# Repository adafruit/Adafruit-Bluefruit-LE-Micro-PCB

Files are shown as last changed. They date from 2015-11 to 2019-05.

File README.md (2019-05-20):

## Adafruit Bluefruit LE Micro PCB (Discontinued)
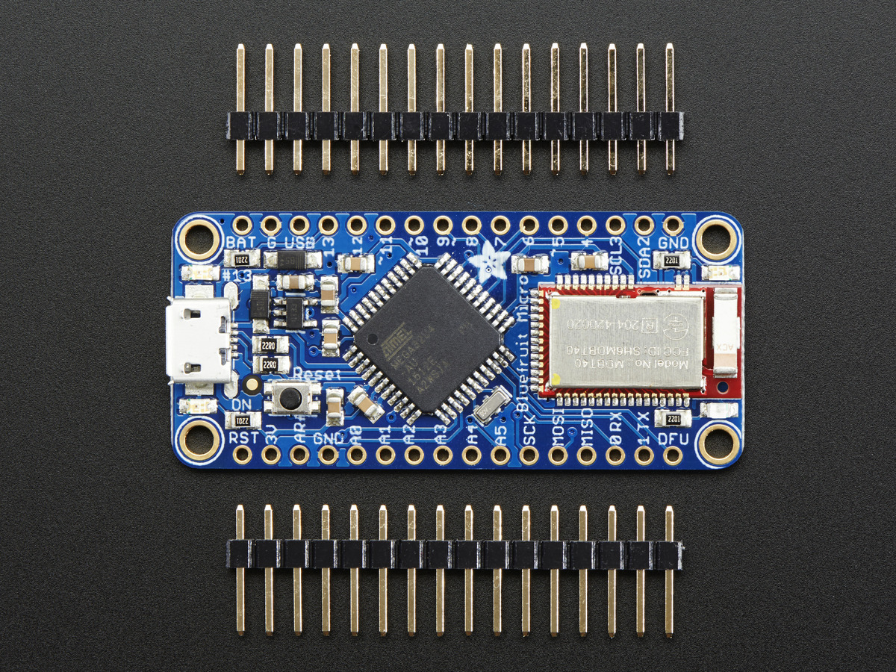
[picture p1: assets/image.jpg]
<a href="http://www.adafruit.com/products/2661"><br/>
See the part listing in the Adafruit shop</a>

DISCONTINUED
Check out the [Adafruit Feather 32u4 Bluefruit LE](https://www.adafruit.com/products/2829), it's an awesome upgrade!

PCB files for Adafruit Bluefruit LE Micro. Format is EagleCAD.
- https://www.adafruit.com/product/2661

### License

Adafruit invests time and resources providing this open source design, please support Adafruit and open-source hardware by purchasing products from [Adafruit](https://www.adafruit.com)!

All text above must be included in any redistribution

Designed by Limor Fried/Ladyada for Adafruit Industries.
Creative Commons Attribution/Share-Alike, all text above must be included in any redistribution. 
See license.txt for additional information.

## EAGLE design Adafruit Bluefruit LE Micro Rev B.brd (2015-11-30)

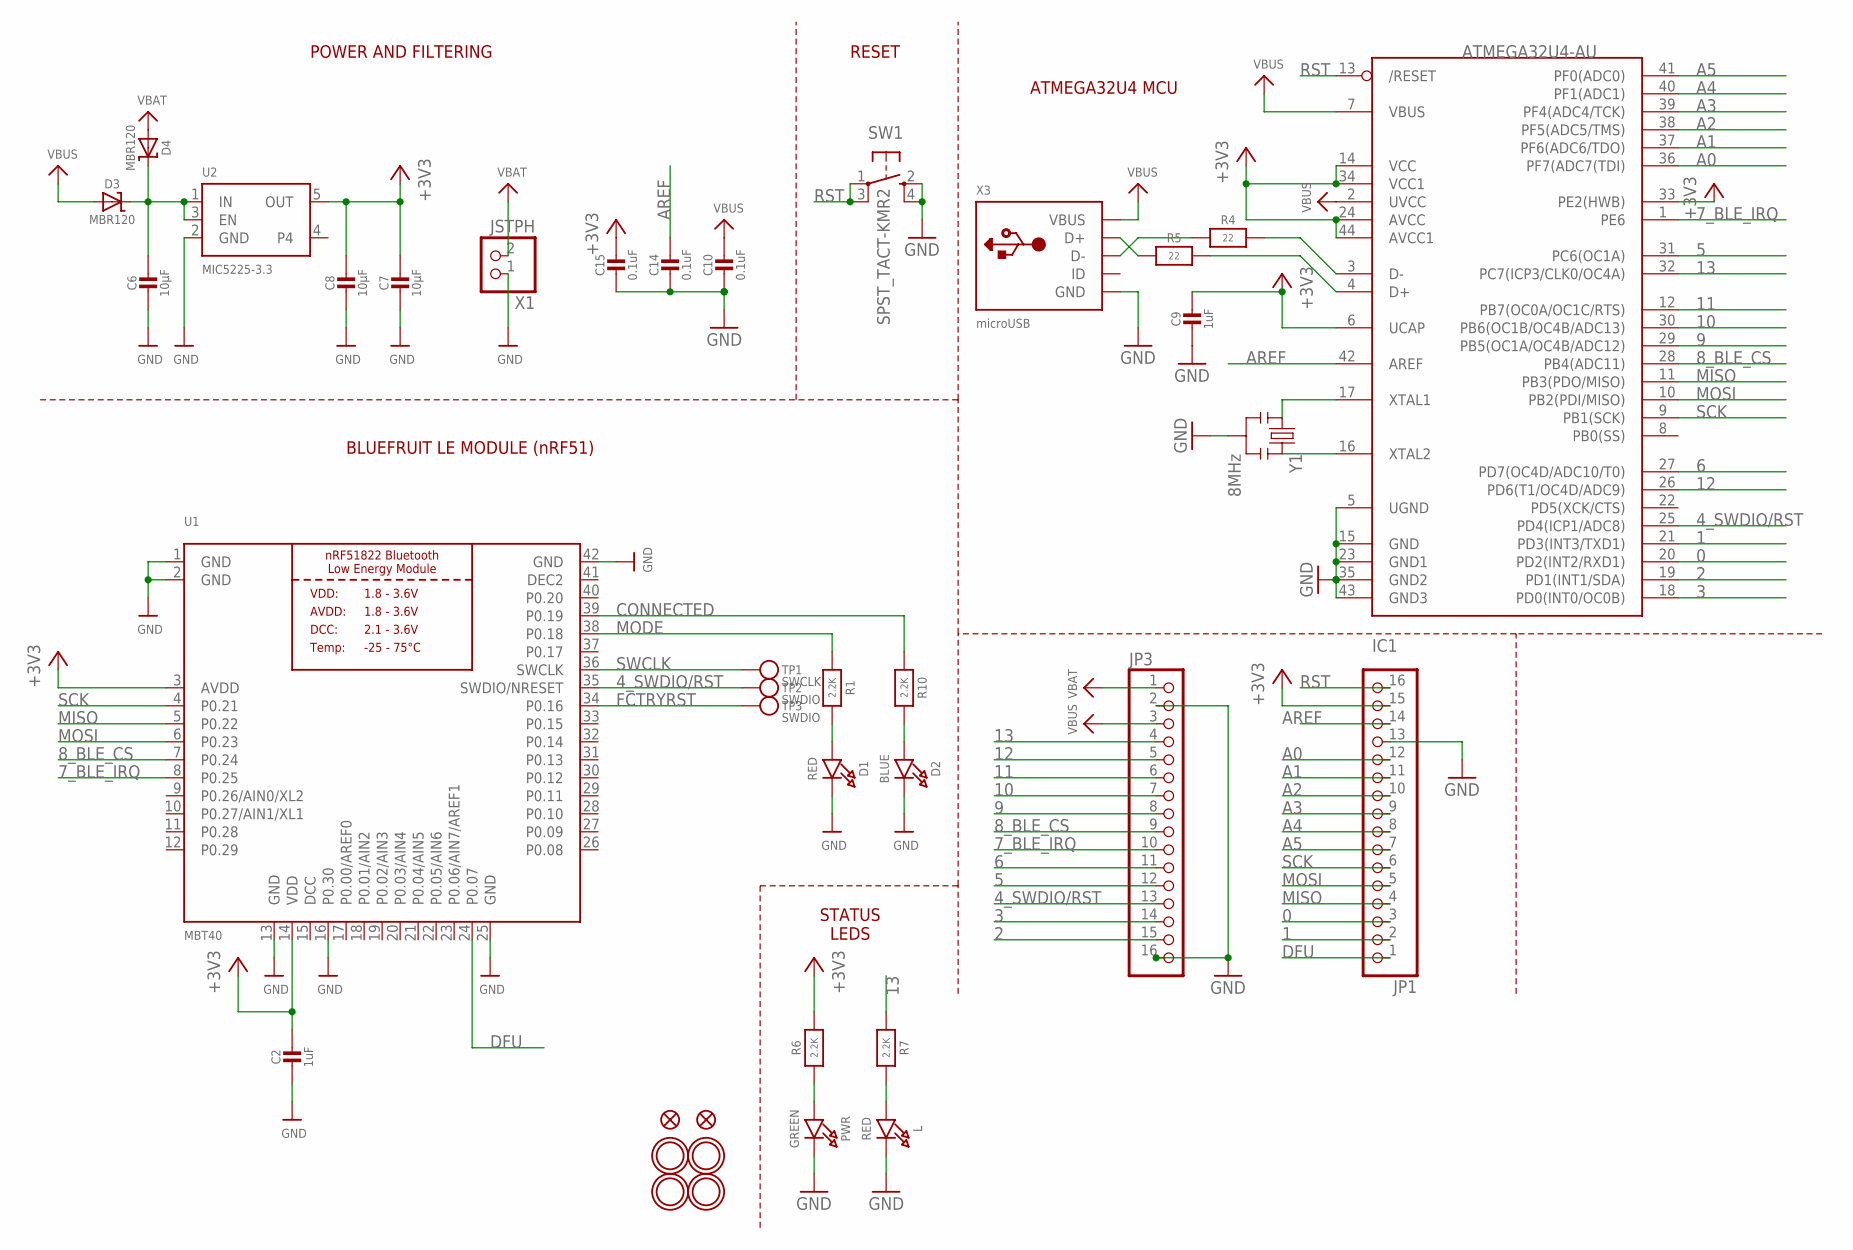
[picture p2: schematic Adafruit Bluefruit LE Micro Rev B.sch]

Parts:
C2, C9: 1uF; 0805-NO
C6: 10µF; _0805MP
C7, C8: 10µF; 0805-NO
C10: 0.1uF; 0805_10MGAP
C14, C15: 0.1uF; 0805-NO
D1: RED; CHIPLED_0805_NOOUTLINE
D2: BLUE; CHIPLED_0805_NOOUTLINE
D3, D4: MBR120; SOD-123
IC1: ATMEGA32U4-AU; TQFP44
JP1, JP3: HEADER-1X16ROUND; 1X16_ROUND
L: RED; CHIPLED_0805_NOOUTLINE
PWR: GREEN; CHIPLED_0805_NOOUTLINE
R1, R6, R7, R10: 2.2K; 0805-NO
R4, R5: 22; 0805-NO
SW1: SPST_TACT-KMR2; KMR2
TP1: SWCLK; PAD-1.5X2.0
TP2, TP3: SWDIO; PAD-1.5X2.0
U1: MBT40; BLE_MODULE_RAYTAC_MDBT40
U2: MIC5225-3.3; SOT23-5
U$6, U$24, U$31, U$32: MOUNTINGHOLE2.5; MOUNTINGHOLE_2.5_PLATED
U$34, U$35: FIDUCIAL""; FIDUCIAL_1MM
X1: JSTPH; JSTPH2
X3: microUSB; 4UCONN_20329
Y1: 8MHz; RESONATOR-SMD

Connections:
0: IC1.20 (PD2(INT2/RXD1)), JP1.3
1: IC1.21 (PD3(INT3/TXD1)), JP1.2
2: IC1.19 (PD1(INT1/SDA)), JP3.15
3: IC1.18 (PD0(INT0/OC0B)), JP3.14
4_SWDIO/RST: IC1.25 (PD4(ICP1/ADC8)), JP3.13, TP2.P$1, U1.35 (SWDIO/NRESET)
5: IC1.31 (PC6(OC1A)), JP3.12
6: IC1.27 (PD7(OC4D/ADC10/T0)), JP3.11
7_BLE_IRQ: IC1.1 (PE6), JP3.10, U1.8 (P0.25)
8_BLE_CS: IC1.28 (PB4(ADC11)), JP3.9, U1.7 (P0.24)
9: IC1.29 (PB5(OC1A/OC4B/ADC12)), JP3.8
10: IC1.30 (PB6(OC1B/OC4B/ADC13)), JP3.7
11: IC1.12 (PB7(OC0A/OC1C/RTS)), JP3.6
12: IC1.26 (PD6(T1/OC4D/ADC9)), JP3.5
13: IC1.32 (PC7(ICP3/CLK0/OC4A)), JP3.4, R7.1
+3V3: C2.1, C7.1, C8.1, C9.1, C15.1, IC1.6 (UCAP), IC1.14 (VCC), IC1.24 (AVCC), IC1.33 (PE2(HWB)), IC1.34 (VCC1), IC1.44 (AVCC1), JP1.15, R6.2, U1.3 (AVDD), U1.14 (VDD), U2.5 (OUT)
A0: IC1.36 (PF7(ADC7(TDI)), JP1.12
A1: IC1.37 (PF6(ADC6/TDO)), JP1.11
A2: IC1.38 (PF5(ADC5/TMS)), JP1.10
A3: IC1.39 (PF4(ADC4/TCK)), JP1.9
A4: IC1.40 (PF1(ADC1)), JP1.8
A5: IC1.41 (PF0(ADC0)), JP1.7
AREF: C14.1, IC1.42 (AREF), JP1.14
CONNECTED: R10.1, U1.39 (P0.19)
DCC: U1.15 (DCC)
DEC2: U1.41 (DEC2)
DFU: JP1.1, U1.24 (P0.07)
FCTRYRST: TP3.P$1, U1.34 (P0.16)
GND: C2.2, C6.2, C7.2, C8.2, C9.2, C10.2, C14.2, C15.2, D1.C, D2.C, IC1.5 (UGND), IC1.15 (GND), IC1.23 (GND1), IC1.35 (GND2), IC1.43 (GND3), JP1.13, JP3.2, JP3.16, L.C, PWR.C, SW1.2 (S), SW1.4 (S1), U1.1 (GND), U1.2 (GND), U1.13 (GND), U1.16 (P0.30), U1.25 (GND), U1.42 (GND), U2.2 (GND), X1.1, X3.BASE@1 (GND), X3.BASE@2 (GND), X3.GND, X3.SPRT@1 (GND), X3.SPRT@2 (GND), X3.SPRT@3 (GND), X3.SPRT@4 (GND), Y1.2
MISO: IC1.11 (PB3(PDO/MISO)), JP1.4, U1.5 (P0.22)
MODE: R1.1, U1.38 (P0.18)
MOSI: IC1.10 (PB2(PDI/MISO)), JP1.5, U1.6 (P0.23)
unnamed: L.A, R7.2
unnamed: D1.A, R1.2
unnamed: D2.A, R10.2
unnamed: IC1.3 (D-), R4.2
unnamed: IC1.4 (D+), R5.2
unnamed: IC1.16 (XTAL2), Y1.3
unnamed: IC1.17 (XTAL1), Y1.1
unnamed: PWR.A, R6.1
unnamed: R5.1, X3.D+
unnamed: R4.1, X3.D-
unnamed: C6.1, D3.C, D4.C, U2.1 (IN), U2.3 (EN)
RST: IC1.13 (/RESET), JP1.16, SW1.1, SW1.3 (P1)
SCK: IC1.9 (PB1(SCK)), JP1.6, U1.4 (P0.21)
SWCLK: TP1.P$1, U1.36 (SWCLK)
VBAT: D4.A, JP3.1, X1.2
VBUS: C10.1, D3.A, IC1.2 (UVCC), IC1.7 (VBUS), JP3.3, X3.VBUS

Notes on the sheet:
POWER AND FILTERING
BLUEFRUIT LE MODULE (nRF51)
RESET
ATMEGA32U4 MCU
STATUS LEDS

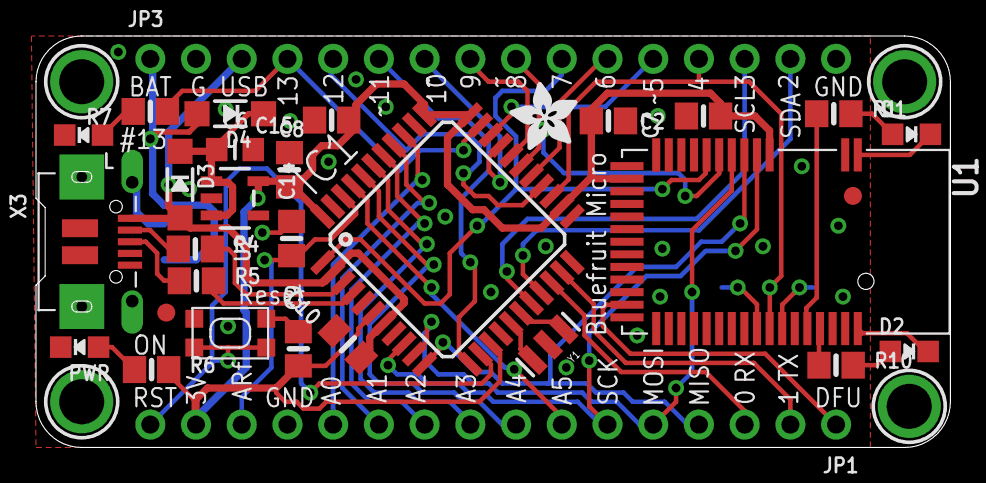
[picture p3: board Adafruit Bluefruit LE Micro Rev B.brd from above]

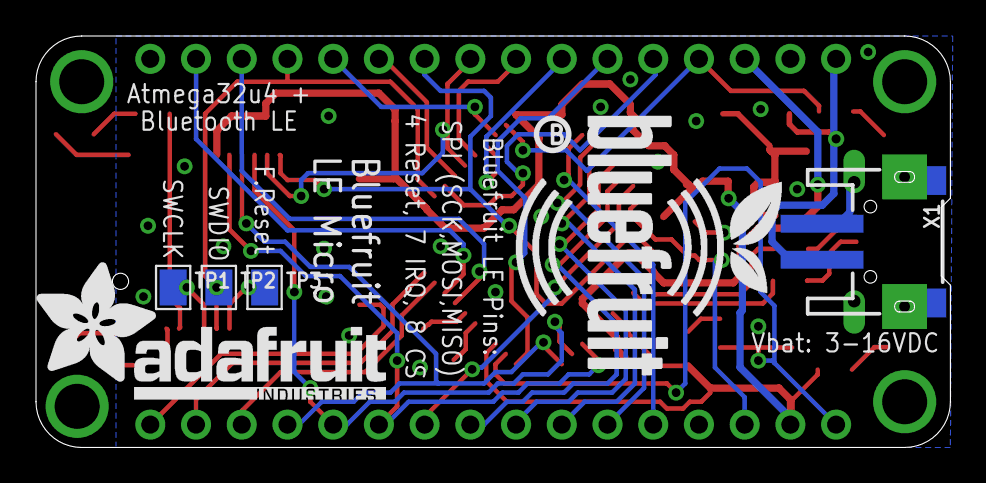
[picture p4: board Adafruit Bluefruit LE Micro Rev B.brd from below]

Board: 2 copper layers, 50.8 x 22.9 mm, 42 parts (7 on the bottom side), 45 nets.

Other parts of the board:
U$7: ADAFRUIT_3.5MM
U$9: ADAFRUIT_TEXT_20MM
U$15: BLUEFRUITLOGO_150MM
U$23: PCBFEAT-REV-040

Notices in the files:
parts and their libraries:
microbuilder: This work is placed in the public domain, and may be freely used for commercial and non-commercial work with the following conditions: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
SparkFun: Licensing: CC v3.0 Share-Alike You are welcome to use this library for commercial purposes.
